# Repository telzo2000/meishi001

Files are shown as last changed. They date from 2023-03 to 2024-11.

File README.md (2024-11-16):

# meishi001

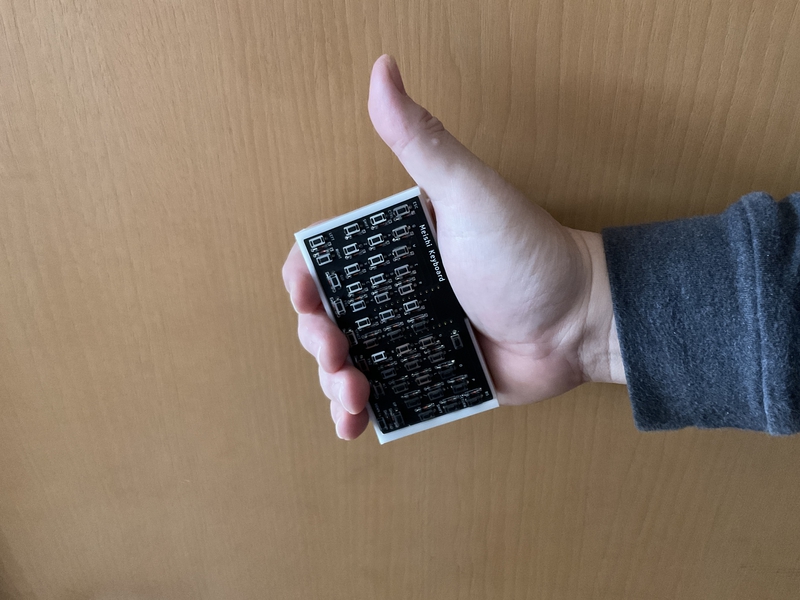
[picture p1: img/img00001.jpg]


This is a repository for Meishi Keyboard.
<br>
Meishi Keyboardのためのリポジトリです。
<br>

Build guide
<br>
https://github.com/telzo2000/meishi001/blob/main/buildguide_for_meishi001_and_002.md
<br>
firmware
<br>
https://github.com/telzo2000/meishi001/tree/main/firmware

<br>

[REMAP](https://remap-keys.app/catalog/LnDFLEBLKVYKpWCBQks4)

<br>

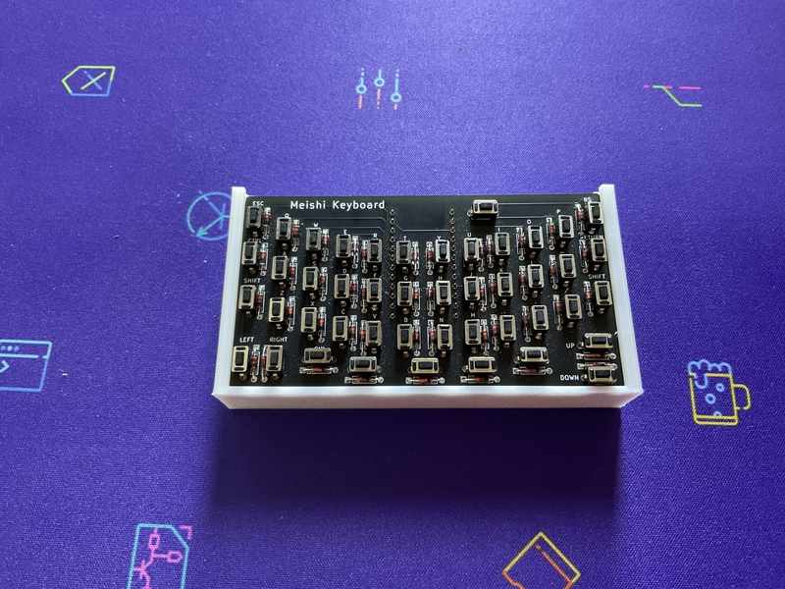
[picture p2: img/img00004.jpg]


# lisence

[CC BY-NC-SA](https://creativecommons.org/licenses/by-nc-sa/4.0/deed.ja)



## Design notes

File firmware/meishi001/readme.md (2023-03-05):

# meishi001

meishi001

*A short description of the keyboard/project*

* Keyboard Maintainer: [m.ki](https://github.com/telzo2000)
* Hardware Supported: *The PCBs, controllers supported*
* Hardware Availability: *Links to where you can find this hardware*

Make example for this keyboard (after setting up your build environment):

    make meishi001:default

Flashing example for this keyboard:

    make meishi001:default:flash

See the [build environment setup](https://docs.qmk.fm/#/getting_started_build_tools) and the [make instructions](https://docs.qmk.fm/#/getting_started_make_guide) for more information. Brand new to QMK? Start with our [Complete Newbs Guide](https://docs.qmk.fm/#/newbs).

## Bootloader

Enter the bootloader in 3 ways:

* **Bootmagic reset**: Hold down the key at (0,0) in the matrix (usually the top left key or Escape) and plug in the keyboard
* **Physical reset button**: Briefly press the button on the back of the PCB - some may have pads you must short instead
* **Keycode in layout**: Press the key mapped to `QK_BOOT` if it is available

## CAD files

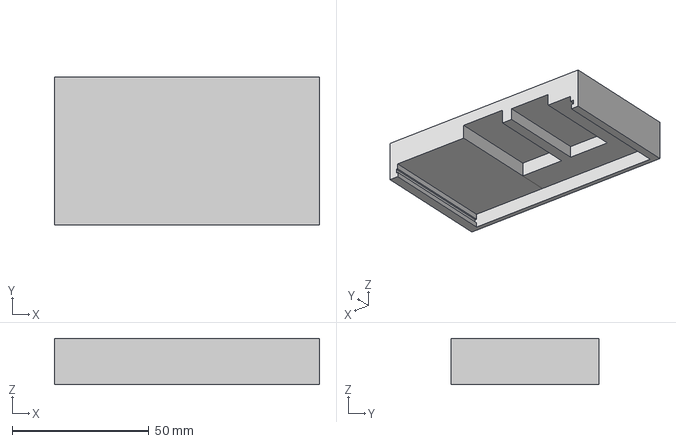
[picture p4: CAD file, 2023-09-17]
3D_case_design/meishi_keyboard_BL_case v9.step
97.0 x 54.0 x 17.0 mm

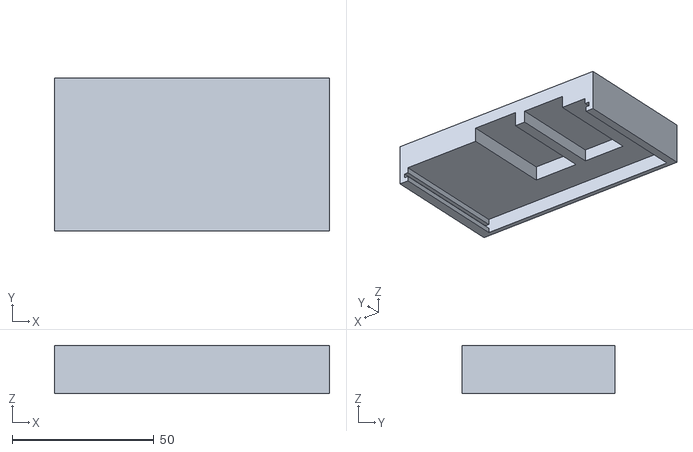
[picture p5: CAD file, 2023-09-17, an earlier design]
3D_case_design/meishi_keyboard_BL_case v8.stl
97.0 x 54.0 x 17.0

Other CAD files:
3D_case_design/meishi_keyboard_case v1.step
3D_case_design/meishi_keyboard_BL_case v2.step
3D_case_design/meishi_keyboard_BL_case v9.stl

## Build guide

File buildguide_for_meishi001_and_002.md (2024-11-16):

# Build guide

## Parts list

| No. | Patrs | Quantity | remarks | Suppliers | Cost |
|--|--|--|--|--|--|
|番号|名前|数|備考|調達先|参考価格（送料込）|<br>
|1|PCB|1|meishi size keyboard|[elecrow](https://www.elecrow.com)<br>[JLCPCB](https://jlcpcb.com)<br>[ALLPCB](https://www.allpcb.com)|５枚で10ドル程度|<br>
|2|pro micro|2|ピンヘッダも別途購入|[遊舎工房](https://yushakobo.jp)<br>[Talp Keyboard](https://talpkeyboard.net)<br>[Daily Craft Keyboard](https://shop.dailycraft.jp)等|価格変動中|
|3|Diode<br>ダイオード|45|リードタイプでもSMDでも可|[遊舎工房](https://yushakobo.jp)<br>[Talp Keyboard](https://talpkeyboard.net)<br>[Daily Craft Keyboard](https://shop.dailycraft.jp)等|100個で220円程度から|
|4|タクトスイッチ|46|２本足のもの|[遊舎工房](https://yushakobo.jp)<br>[Talp Keyboard](https://talpkeyboard.net)<br>[Daily Craft Keyboard](https://shop.dailycraft.jp)等|１個11円程度|

In addition, you will need a TRRS cable, USB cable, keycaps, etc.
<br>
この他に、USBケーブルが必要です。
<br>

## Firmware

###  QMK_FIRMWARE

参考<br>

https://github.com/telzo2000/Hello_keyboard/blob/main/readme_about_firmware.md

[Here](https://github.com/telzo2000/meishi001/tree/main/firmware)

<br>
[remap](https://remap-keys.app/catalog/LnDFLEBLKVYKpWCBQks4)

<br>

## Build 

### 1 Diode soldering

Insert the diode from the front side of the PCB and solder it to the back side.
<br>
PCBの表面からダイオードを差して、裏面にハンダ付けをします。
<br>

There are lead type and SMD diodes.
<br>
ダイオードはリードタイプか、SMDがあります。
<br>
Here, we will explain the lead type soldering.
<br>
ここでは、リードタイプのハンダ付けの説明をします。
<br>
Use a lead bender to bend the legs of the diode.
<br>
リードベンダーを使い、ダイオードの足を曲げます。
<br>

Insert the diode into the board.
<br>
ダイオードを基板に挿しこみます。
<br>

Please pay attention to the orientation of the diode.
<br>
ダイオードの向きに注意してください。
<br>

Secure the diode with masking tape, then face up.
<br>
マスキングテープでダイオードを固定してから、表面を上にします。
<br>
Solder the protruding legs.
<br>
はみ出ている足部分に、ハンダ付けをします。
<br>
After soldering, use nippers to cut off the protruding legs.
<br>
はんだ付けが終わったら、はみ出ている足をニッパーで切り取ってください。
<br>

[８倍速　Diodeハンダ付け動画](https://youtu.be/Yaodh2-XxV4)

<br>
<br>

### 2 Tactswitch soldering

Insert the tactswitch on the surface.
<br>
表面にタクトスイッチを挿しこみます。
<br>
Solder the legs of the tactswitch from the back.
<br>
裏面からタクトスイッチの足をハンダ付けします。
<br>

#### 3 pro micro

The side on which the parts of the pro micro are mounted is the surface. The opposite side is the back side.
<br>
pro microの部品が実装されている面を表面とします。反対の面を裏面とします。
<br>

The pro micro attaches to the back side of the PCB.
<br>
pro microは、PCBの裏面に取り付けます。
<br>
At that time, attach it so that the front surface of the pro micro and the back surface of the PCB face each other.
<br>
その際、pro microの表面とPCBの裏面が向かい合うように取り付けます。
<br>
Please use the cons through while considering removal. If not, please solder it with a pin header.
<br>
取り外しを考えるながら、コンスルーを利用してください。　そうでなければ、ピンヘッダでハンダ付けしてください。
<br>
Just install the firmware and you're done. If you like, print the case with a 3D printer and attach it.
<br>
あとはファームウェアを入れて完成です。お好みで3Dプリンタでケースを印刷して付けてください。
<br>

### Option (Ble Micro)

<br>
meishi002 is compatible with Ble Micro. Please prepare Ble Micro and battery board sold at Yusha Kobo.
<br>
meishi002はBle Microに対応しています。遊舎工房で販売しているBle Micro及び電池基板を用意してください。

Ble micro

https://shop.yushakobo.jp/products/ble-micro-pro?_pos=1&_sid=89874baf6&_ss=r

電池基板

https://shop.yushakobo.jp/products/ble-micro-pro-battery-board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

<br>
Attach each to the back side of the PCB.
<br>
それぞれをPCBの裏面に取り付けてください。
<br>
Please take full responsibility for the implementation of Ble Micro. The author is not detailed enough to answer all questions.
<br>
Ble Microの実装については、自己責任でお願いします。作者は全ての質問に答えられるほど、詳しくありません。
